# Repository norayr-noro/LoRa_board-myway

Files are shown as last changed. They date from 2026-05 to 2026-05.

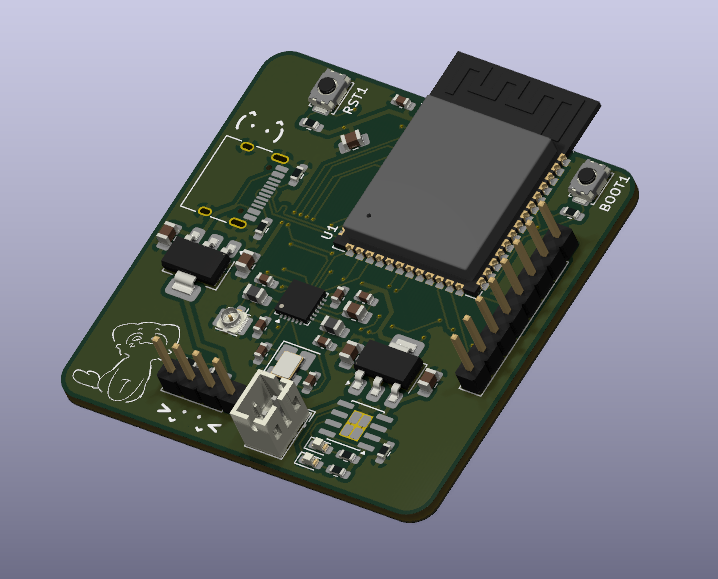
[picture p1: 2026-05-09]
photosss/PCB_lora(3d).png

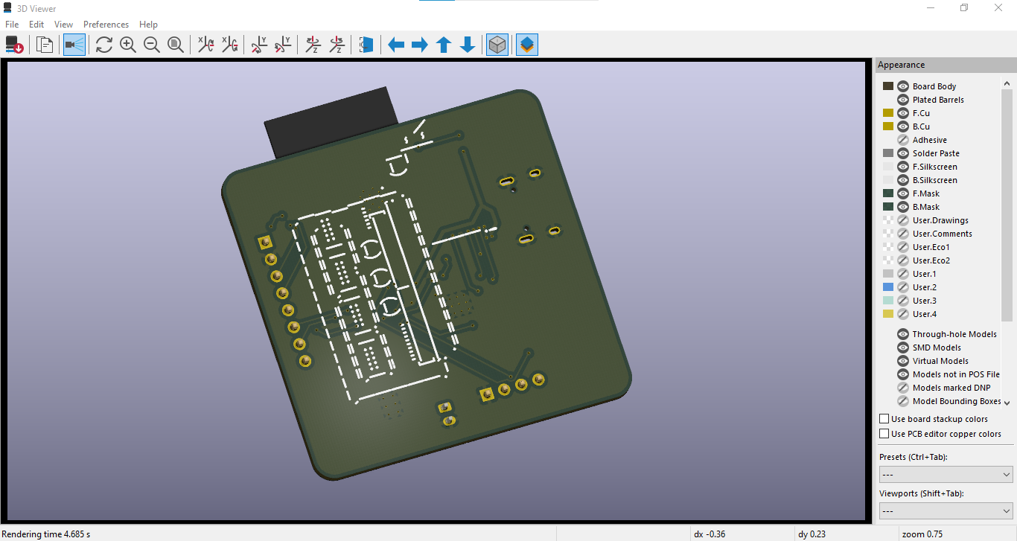
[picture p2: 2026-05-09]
photosss/PCB_lora(3d-back).png

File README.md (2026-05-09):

# LoRa_board-myway
For this project, I'll be designing the schematic and a custom PCB from that schematic based on the Stasis Meshtastic LoRa Board starter guide. The difference between mine and the guide's board is that mine adds the PCB to be able to charge from a simple LiPo battery  (and don't forget the silkscreen art on the PCB!!)

# Overview
In short, I'll be using the guide from Hack Club Stasis starter projects ( [https://stasis.hackclub.com/starter-projects/devboard](https://stasis.hackclub.com/starter-projects/meshtastic-lora) ), of which I'll be using the same ESP32 WROOM-1 chip, which is the same chip used in most ESP32-based boards, and would act as the main thing in the build + an S1262 radio chip to be able to communicate and send data using the Meshtastic system. By using this guide, I made my own basic LoRa board and added extra functionality to it!!!!

# 🛠️ Design & Components 
In my design, I have used:

Footprints_2

Footprints_1
# ⚙️ Tools & Process
Using the base guide on stasis, I created a schematic template for my devboard. After which I added my own things to the devboard, including a fully functional battery module to the PCB using a TP4056 and an AMS1117-3.3 module to make the connection a JST pin header to connect it to the battery itself. And also added silkscreen to make the project feel more alive in a way (idk).

# 📈 Progress
After the schematic was completed, the project entered the PCB stage. This was quite difficult at first, trying to cram all of this into such a small profile, so the prototype model of the PCB did not look that great. Knowing this would not be sufficient for submition i did a complete re-work of the PCB and learnt a few things doing it, that the storage decoupling capacitors and the crystal oscillator should be really close to not cause errors in their own cases. After all of that horror of a long time spend trying to figure things out I think the project overall went ok. Heres a few photos of how the final project looks:

PCB_lora(3d)
PCB_lora(3d-back)

# 💭 Final Thoughts + Conclusion
Overall, this project was unexpectedly difficult, but it was fun understanding how a radio board like this worked, and it was quite interesting to learn how the Meshtastic system connections worked. Can't wait to actually see my final built project!!!

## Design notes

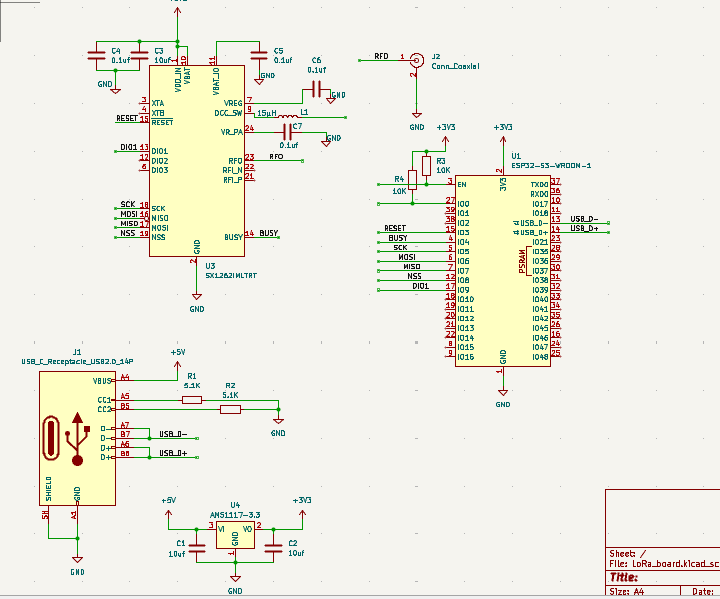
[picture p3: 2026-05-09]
photosss/Screenshot 2026-05-04 111854.png

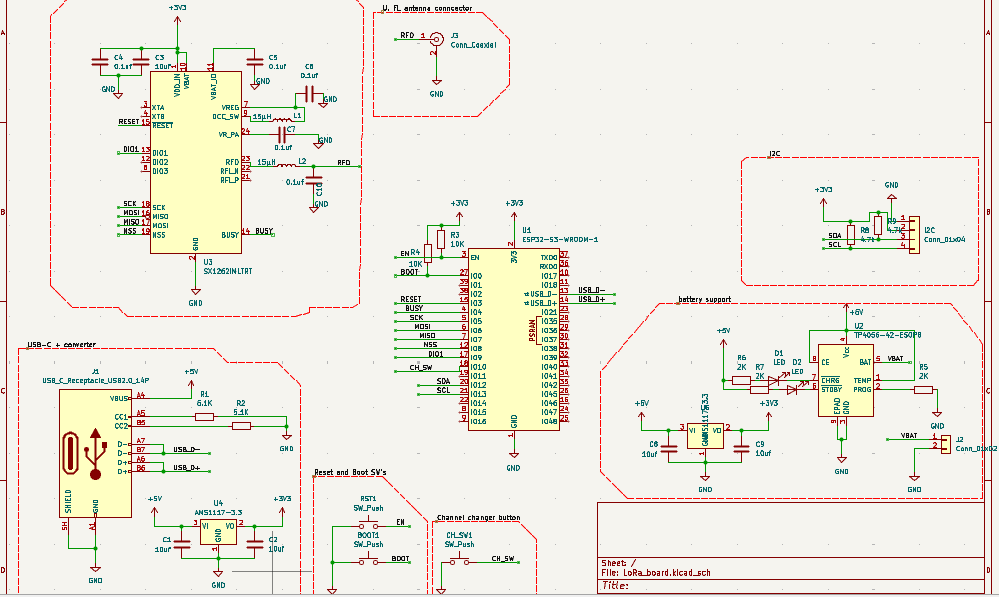
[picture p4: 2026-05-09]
photosss/Screenshot 2026-05-04 192957.png

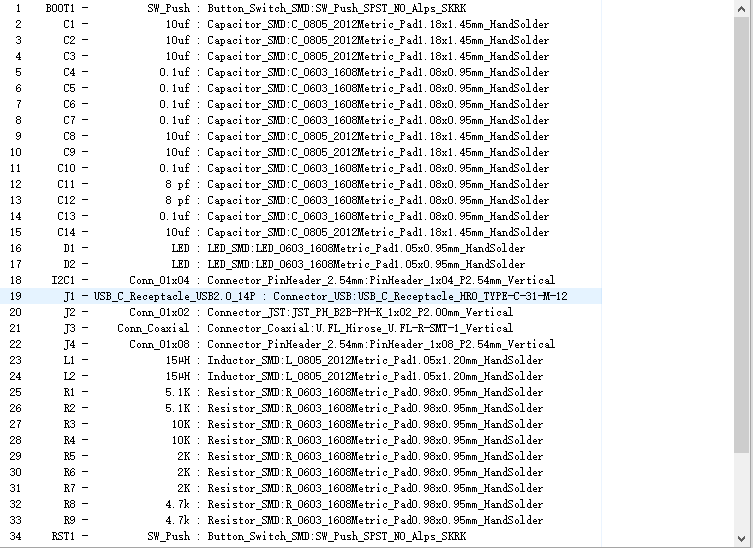
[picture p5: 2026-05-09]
photosss/Footprints_2.png

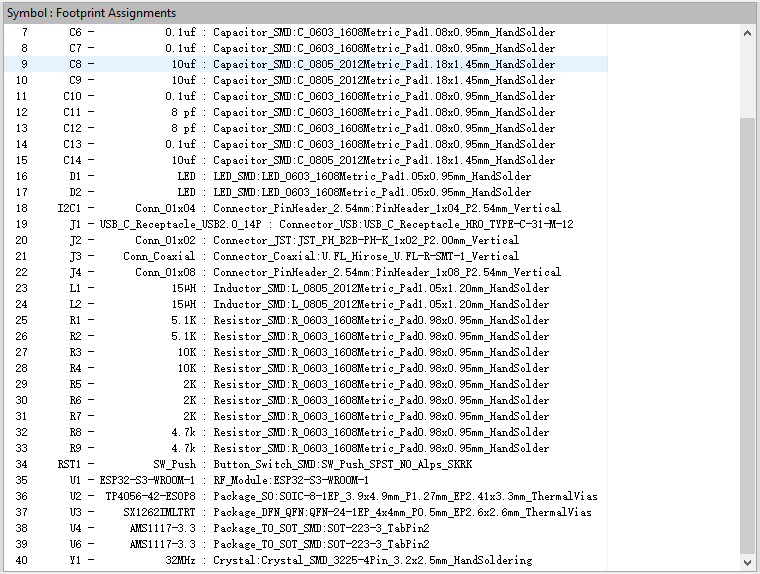
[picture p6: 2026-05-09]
photosss/Footprints_1.png

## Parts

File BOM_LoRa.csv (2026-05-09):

 | Price valued per unit and total price, Assembled (in USD)
Item | URL | Price (per unit ) | Quantity needed | Quantity to order | Total
buttons SW_Push | https://jlcpcb.com/partdetail/XUNPU-TS_1088AR02016/C720477 | 0.0556 | 2 | 4 | 0.2224
10uf capcitors | https://jlcpcb.com/partdetail/439567-GRM21BR61H106KE43L/C440198 | 0.0681 | 6 | 12 | 0.8172
0.1 uf capacitors | https://jlcpcb.com/partdetail/YAGEO-CC0603KRX7R9BB104/C14663 | 0.003 | 6 | 12 | 0.036
8pf capacitors | https://jlcpcb.com/partdetail/37486-0603CG8R0C500NT/C36508 | 0.0038 | 2 | 20 | 0.076
LED smd | https://jlcpcb.com/partdetail/Hubei_KENTOElec-KT0603W/C2290 | 0.012 | 2 | 4 | 0.048
USB-C receptacle | https://jlcpcb.com/partdetail/Korean_HropartsElec-TYPE_C_31_M12/C165948 | 0.1836 | 1 | 2 | 0.3672
U. FL connector | https://www.tme.eu/gb/details/u.fl-r-smt-01-/micro-connectors/hirose/u-fl-r-smt-01/?brutto=1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 | 1.76 | 1 | 1 | 1.76
15 uH inductors | https://jlcpcb.com/partdetail/76759-CMI201209J150KT/C75634 | 0.038 | 2 | 20 | 0.76
5.1K resitors | https://jlcpcb.com/partdetail/23913-0603WAF5101T5E/C23186 | 0.0016 | 2 | 4 | 0.0064
10K resitors | https://jlcpcb.com/partdetail/26547-0603WAF1002T5E/C25804 | 0.0031 | 2 | 4 | 0.0124
2K resistors | https://jlcpcb.com/partdetail/23702-0603WAF2001T5E/C22975 | 0.0017 | 3 | 6 | 0.0102
4.7K resitors | https://jlcpcb.com/partdetail/23889-0603WAF4701T5E/C23162 | 0.0013 | 2 | 4 | 0.0052
ESP32-S3-WROOM-1 | https://www.tme.eu/gb/details/esp32-wroom-32e/iot-wifi-bluetooth-modules/espressif/esp32-wroom-32e-n4/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 | 4.44 | 1 | 1 | 4.44
TP4056-42-ESOP8 | https://jlcpcb.com/partdetail/17264-TP4056_42ESOP8/C16581 | 0.1852 | 1 | 2 | 0.3704
SX1262IMLTRT | https://jlcpcb.com/partdetail/SEMTECH-SX1262IMLTRT/C191341 | 3.207 | 1 | 2 | 6.144
AMS1117-3.3 | https://jlcpcb.com/partdetail/Advanced_MonolithicSystems-AMS1117_33/C6186 | 0.2123 | 2 | 4 | 0.8492
32MHZ crystal | https://jlcpcb.com/partdetail/Huiyuancrystal-HY32MSMD2520CA1R30/C5265851 | 0.121 | 1 | 5 | 0.605
Subtotal (only parts) | 16.53
Shipping and handling (US to UK) | 21
PCB | 4
Total (without assembly fees) | 20.53
Total (with fees) | 40.8

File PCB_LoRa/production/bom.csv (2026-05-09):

Designator | Footprint | Quantity | Value | LCSC Part #
BOOT1, RST1 | SW_Push_SPST_NO_Alps_SKRK | 2 | SW_Push
C1, C14, C2, C3, C8, C9 | 0805 | 6 | 10uf
C10, C13, C4, C5, C6, C7 | 0603 | 6 | 0.1uf
C11, C12 | 0603 | 2 | 8 pf
D1, D2 | 0603 | 2 | LED
I2C1 | PinHeader_1x04_P2.54mm_Vertical | 1 | Conn_01x04
J1 | USB_C_Receptacle_HRO_TYPE-C-31-M-12 | 1 | USB_C_Receptacle_USB2.0_14P
J2 | JST_PH_B2B-PH-K_1x02_P2.00mm_Vertical | 1 | Conn_01x02
J3 | U.FL_Hirose_U.FL-R-SMT-1_Vertical | 1 | Conn_Coaxial
J4 | PinHeader_1x08_P2.54mm_Vertical | 1 | Conn_01x08
L1, L2 | 0805 | 2 | 15µH
R1, R2 | 0603 | 2 | 5.1K
R3, R4 | 0603 | 2 | 10K
R5, R6, R7 | 0603 | 3 | 2K
R8, R9 | 0603 | 2 | 4.7k
U1 | ESP32-S3-WROOM-1 | 1 | ESP32-S3-WROOM-1
U2 | SOIC-8-1EP_3.9x4.9mm_P1.27mm_EP2.41x3.3mm_ThermalVias | 1 | TP4056-42-ESOP8
U3 | QFN-24-1EP_4x4mm_P0.5mm_EP2.6x2.6mm_ThermalVias | 1 | SX1262IMLTRT
U4, U6 | SOT-223-3_TabPin2 | 2 | AMS1117-3.3
Y1 | Crystal_SMD_3225-4Pin_3.2x2.5mm_HandSoldering | 1 | 32MHz

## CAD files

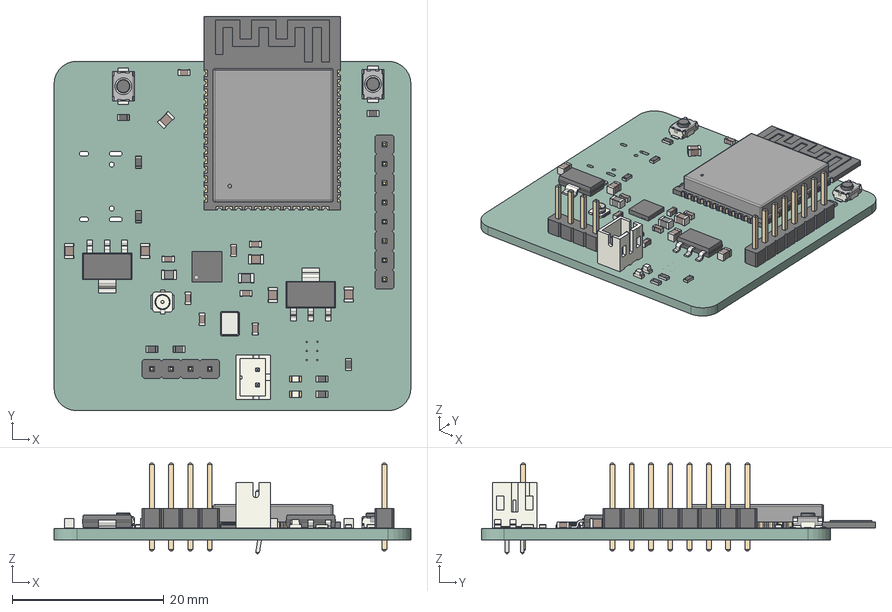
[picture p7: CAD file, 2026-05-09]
PCB_LoRa/LoRa_board(a).step
47.0 x 51.9 x 11.9 mm
SW_Push_SPST_NO_Alps_SKRK x 2
SOT-223 x 2
PinHeader_1x08_P2.54mm_Vertical
R_0603_1608Metric x 9
QFN-24-1EP_4x4mm_P0.5mm_EP2.6x2.6mm
L_0805_2012Metric x 2
C_0603_1608Metric x 8
C_0805_2012Metric x 6
LED_0603_1608Metric x 2
PinHeader_1x04_P2.54mm_Vertical
Crystal_SMD_3225-4Pin_3.2x2.5mm
ESP32-S3-WROOM-1
JST_PH_B2B-PH-K_1x02_P2.00mm_Vertical
U.FL_Hirose_U.FL-R-SMT-1_Vertical
LoRa_board_PCB

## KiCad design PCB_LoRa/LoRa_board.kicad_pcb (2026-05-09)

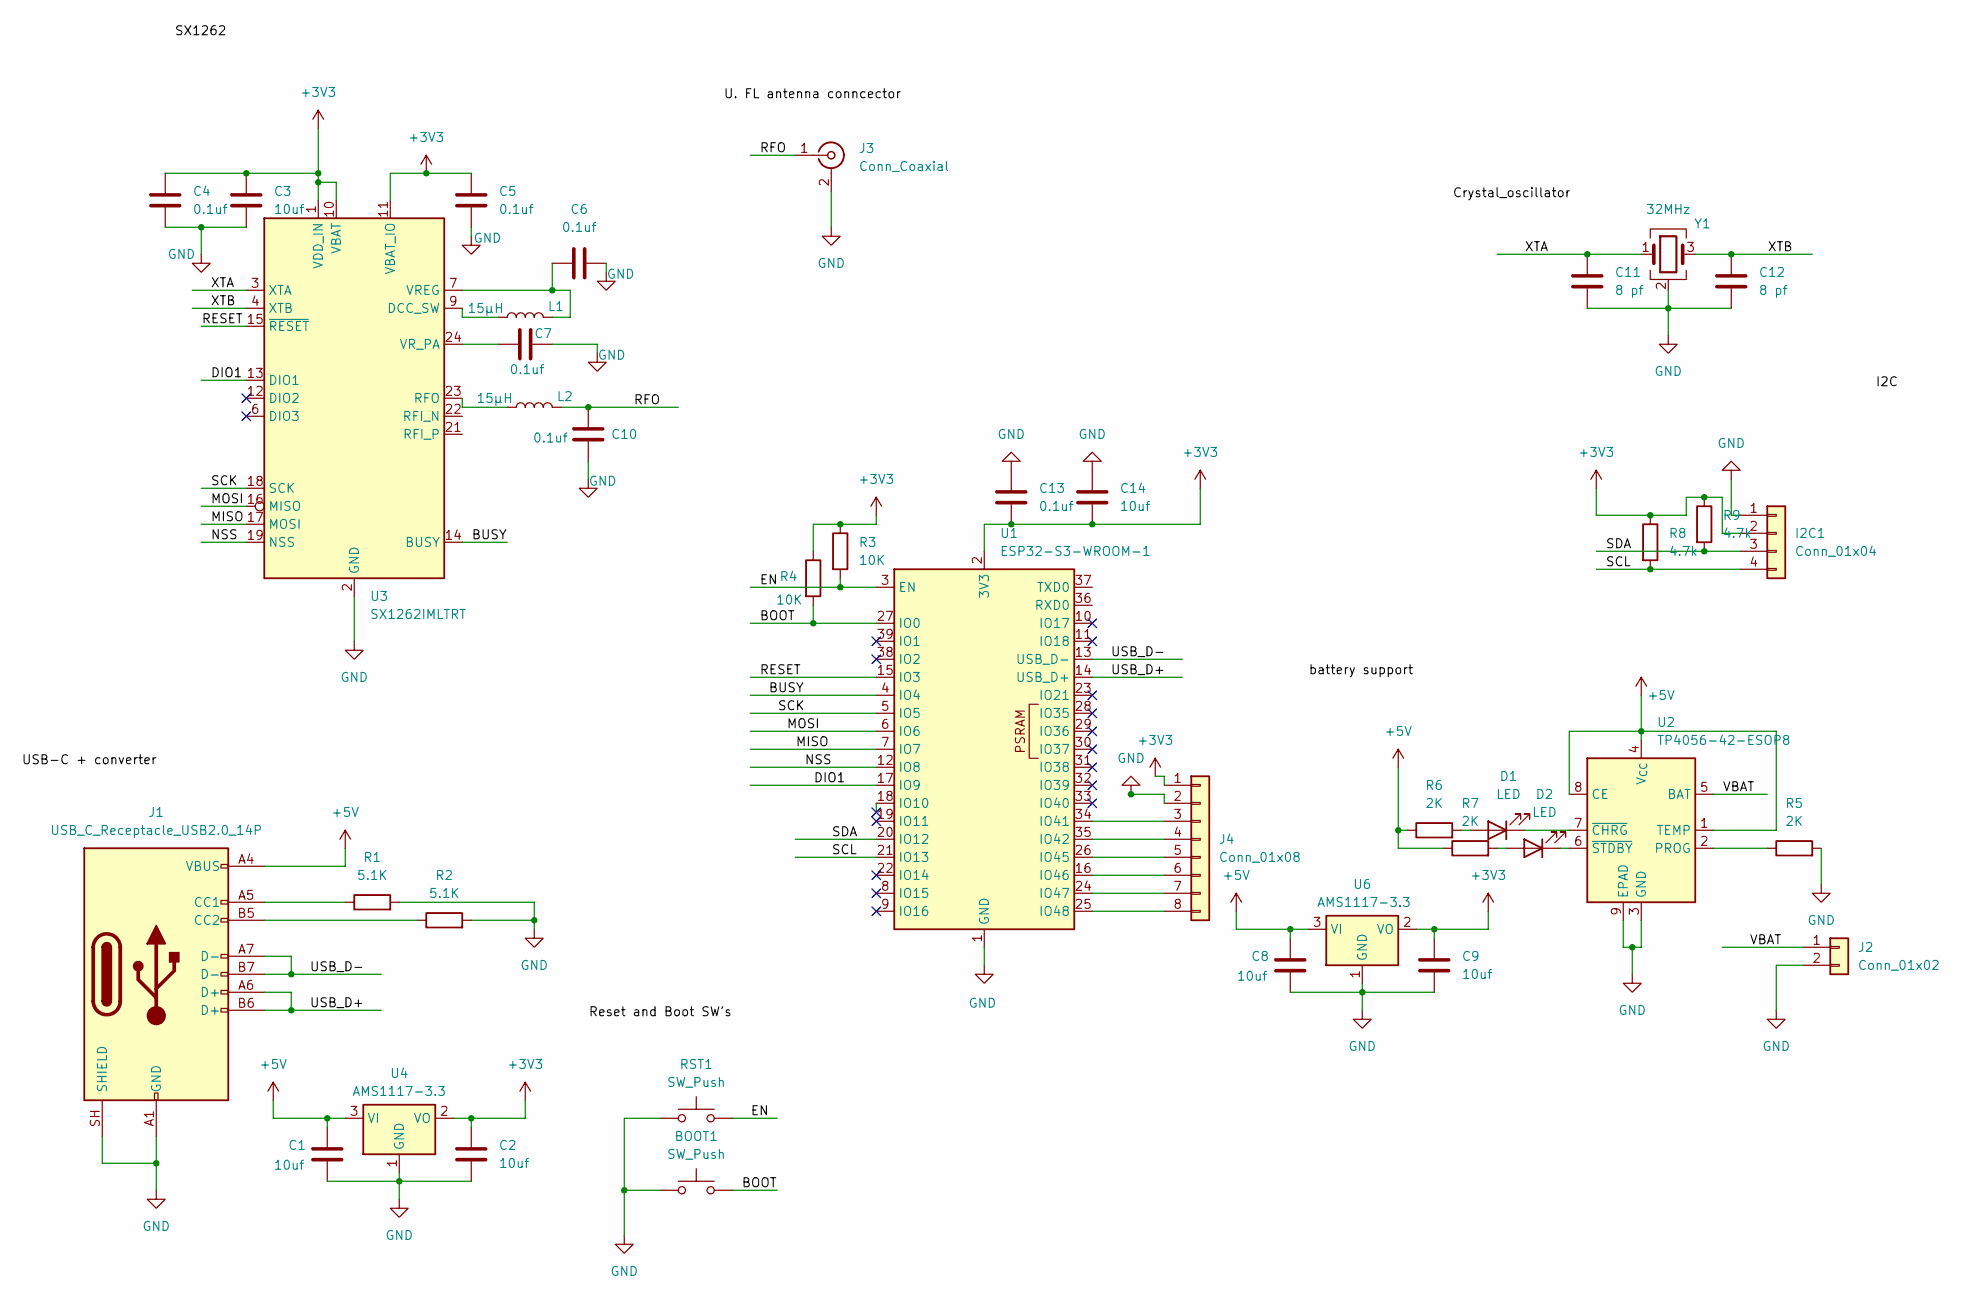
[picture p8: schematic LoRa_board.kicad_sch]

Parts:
BOOT1: SW_Push; SW_Push_SPST_NO_Alps_SKRK
C1, C2, C3, C8, C9, C14: 10uf; C_0805_2012Metric_Pad1.18x1.45mm_HandSolder
C4, C5, C6, C7, C10, C13: 0.1uf; C_0603_1608Metric_Pad1.08x0.95mm_HandSolder
C11, C12: 8 pf; C_0603_1608Metric_Pad1.08x0.95mm_HandSolder
D1, D2: LED; LED_0603_1608Metric_Pad1.05x0.95mm_HandSolder
I2C1: Conn_01x04; PinHeader_1x04_P2.54mm_Vertical
J1: USB_C_Receptacle_USB2.0_14P; USB_C_Receptacle_HRO_TYPE-C-31-M-12
J2: Conn_01x02; JST_PH_B2B-PH-K_1x02_P2.00mm_Vertical
J3: Conn_Coaxial; U.FL_Hirose_U.FL-R-SMT-1_Vertical
J4: Conn_01x08; PinHeader_1x08_P2.54mm_Vertical
L1, L2: 15µH; L_0805_2012Metric_Pad1.05x1.20mm_HandSolder
R1, R2: 5.1K; R_0603_1608Metric_Pad0.98x0.95mm_HandSolder
R3, R4: 10K; R_0603_1608Metric_Pad0.98x0.95mm_HandSolder
R5, R6, R7: 2K; R_0603_1608Metric_Pad0.98x0.95mm_HandSolder
R8, R9: 4.7k; R_0603_1608Metric_Pad0.98x0.95mm_HandSolder
RST1: SW_Push; SW_Push_SPST_NO_Alps_SKRK
U1: ESP32-S3-WROOM-1
U2: TP4056-42-ESOP8; SOIC-8-1EP_3.9x4.9mm_P1.27mm_EP2.41x3.3mm_ThermalVias
U3: SX1262IMLTRT; QFN-24-1EP_4x4mm_P0.5mm_EP2.6x2.6mm_ThermalVias
U4, U6: AMS1117-3.3; SOT-223-3_TabPin2
Y1: 32MHz; Crystal_SMD_3225-4Pin_3.2x2.5mm_HandSoldering

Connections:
+3V3: C2.1, C3.1, C4.1, C5.1, C9.1, C13.2, C14.2, I2C1.2, J4.1, R3.1, R4.1, R8.1, R9.1, U1.2 (3V3), U3.1 (VDD_IN), U3.10 (VBAT), U3.11 (VBAT_IO), U4.2 (VO), U6.2 (VO)
+5V: C1.1, C8.1, J1.A4 (VBUS), J1.A9 (VBUS), J1.B4 (VBUS), J1.B9 (VBUS), R6.1, R7.1, U2.1 (TEMP), U2.4 (V_{CC}), U2.8 (CE), U4.3 (VI), U6.3 (VI)
/BOOT: BOOT1.2, R4.2, U1.27 (IO0)
/BUSY: U1.4 (IO4), U3.14 (BUSY)
/DIO1: U1.17 (IO9), U3.13 (DIO1)
/EN: R3.2, RST1.2, U1.3 (EN)
/MISO: U1.7 (IO7), U3.17 (MOSI)
/MOSI: U1.6 (IO6), U3.16 (MISO)
/NSS: U1.12 (IO8), U3.19 (NSS)
/RESET: U1.15 (IO3), U3.15 (~RESET)
/RFO: C10.1, J3.1 (In), L2.2
/SCK: U1.5 (IO5), U3.18 (SCK)
/SCL: I2C1.4, R8.2, U1.21 (IO13)
/SDA: I2C1.3, R9.2, U1.20 (IO12)
/USB_D+: J1.A6 (D+), J1.B6 (D+), U1.14 (USB_D+)
/USB_D-: J1.A7 (D-), J1.B7 (D-), U1.13 (USB_D-)
/VBAT: J2.1, U2.5 (BAT)
/XTA: C11.1, U3.3 (XTA), Y1.1
/XTB: C12.1, U3.4 (XTB), Y1.3
GND: BOOT1.1, C1.2, C2.2, C3.2, C4.2, C5.2, C6.2, C7.2, C8.2, C9.2, C10.2, C11.2, C12.2, C13.1, C14.1, I2C1.1, J1.A1 (GND), J1.A12 (GND), J1.B1 (GND), J1.B12 (GND), J1.SH (SHIELD), J2.2, J3.2 (Ext), J4.2, R1.2, R2.2, R5.2, RST1.1, U1.1 (GND), U1.40 (GND), U1.41 (GND), U2.3 (GND), U2.9 (EPAD), U3.2 (GND), U3.5 (GND), U3.8 (GND), U3.20 (GND), U3.25 (GND), U4.1 (GND), U6.1 (GND), Y1.2 (G), Y1.4 (G)
unnamed: D1.2 (A), R6.2
unnamed: D1.1 (K), U2.7 (~CHRG)
unnamed: D2.2 (A), R7.2
unnamed: D2.1 (K), U2.6 (~STDBY)
unnamed: J1.A5 (CC1), R1.1
unnamed: J1.B5 (CC2), R2.1
unnamed: J4.3, U1.34 (IO41)
unnamed: J4.4, U1.35 (IO42)
unnamed: J4.5, U1.26 (IO45)
unnamed: J4.6, U1.16 (IO46)
unnamed: J4.7, U1.24 (IO47)
unnamed: J4.8, U1.25 (IO48)
unnamed: R5.1, U2.2 (PROG)
unnamed: L1.1, U3.9 (DCC_SW)
unnamed: L2.1, U3.23 (RFO)
unnamed: C6.1, L1.2, U3.7 (VREG)
unnamed: C7.1, U3.24 (VR_PA)

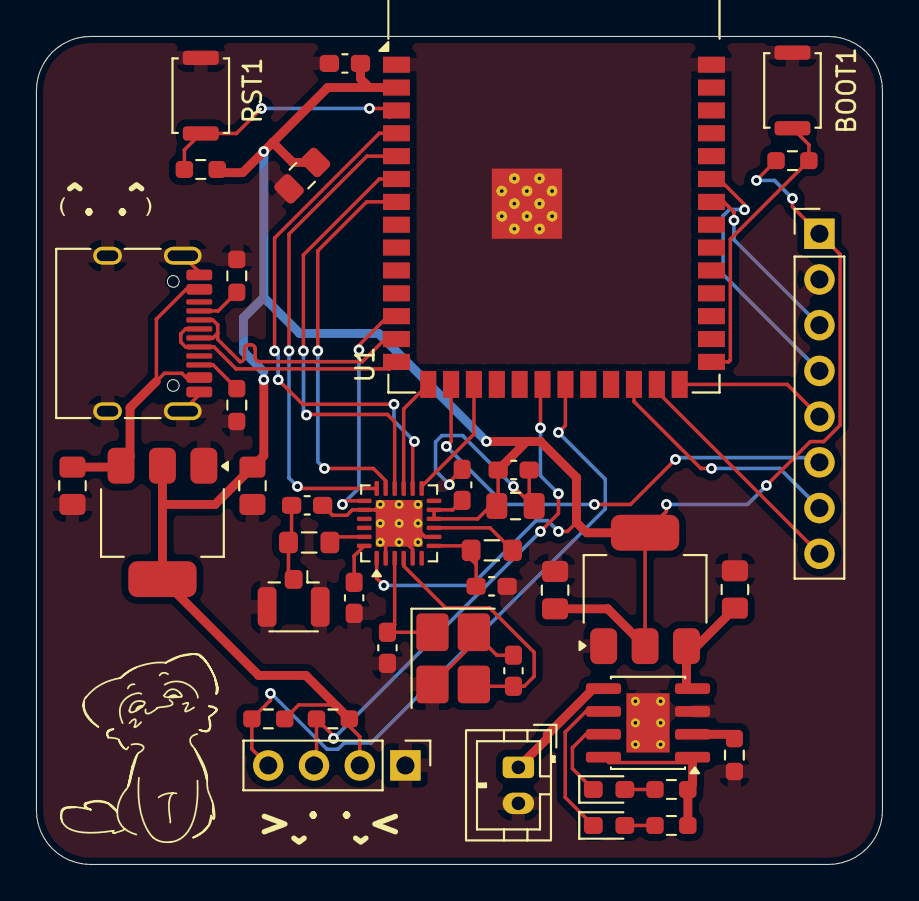
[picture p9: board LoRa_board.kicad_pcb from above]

Board: 2 copper layers, 47.0 x 46.0 mm, 40 parts (0 on the bottom side), 37 nets.
